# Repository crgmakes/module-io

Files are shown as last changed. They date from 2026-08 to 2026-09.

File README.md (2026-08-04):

# I/O Module

All the source files for the I/O module hardware.

# Software 

You will need [KiCad](https://kicad.org) to view and edit this design. Click [here](https://www.kicad.org/download/) to download.

You will also need all the associated libraries and models to drive the design if you want to make changes or view the 3D rendering:

https://github.com/crgmakes/kicad-library.git

Kicad MUST be configured properly to use all the files in this repo. Once you have Kicad installed, under Preferences->Configure Paths..., make the following entries:

1. KICAD_USER_DIR -> set to the root location of where you placed the above repository.
2. KICAD_USER_LIBRARY = ${KICAD_USER_DIR}/Library
3. KICAD_USER_MODEL_DIR = ${KICAD_USER_LIBRARY}/models
4. KICAD_USER_TEMPLATE_DIR = ${KICAD_USER_LIBRARY}/templates	

Kicad will operate mostly normally if these are not set properly. You will notice an issue when you view the PCB in 3D mode.

***NOTE***: after makeing a release build in git, if your rendered 3D images are missing components, ensure the path to EVERY component model is set to ${KICAD_USER_MODEL_DIR}/<model name>.

Kicad sometimes replaces the variable with an expansion and that FAILS during the build process because the expanded variable is local and does not match the build environment.

---

THE DESIGN IS PROVIDED "AS IS" AND THE AUTHOR DISCLAIMS ALL WARRANTIES WITH REGARD TO THIS DESIGN INCLUDING ALL IMPLIED WARRANTIES OF MERCHANTABILITY AND FITNESS. IN NO EVENT SHALL THE AUTHOR BE LIABLE FOR ANY SPECIAL, DIRECT, INDIRECT, OR CONSEQUENTIAL DAMAGES OR ANY DAMAGES WHATSOEVER RESULTING FROM LOSS OF USE, DATA OR PROFITS, WHETHER IN AN ACTION OF CONTRACT, NEGLIGENCE OR OTHER TORTIOUS ACTION, ARISING OUT OF OR IN CONNECTION WITH THE USE OR PERFORMANCE OF THIS DESIGN.

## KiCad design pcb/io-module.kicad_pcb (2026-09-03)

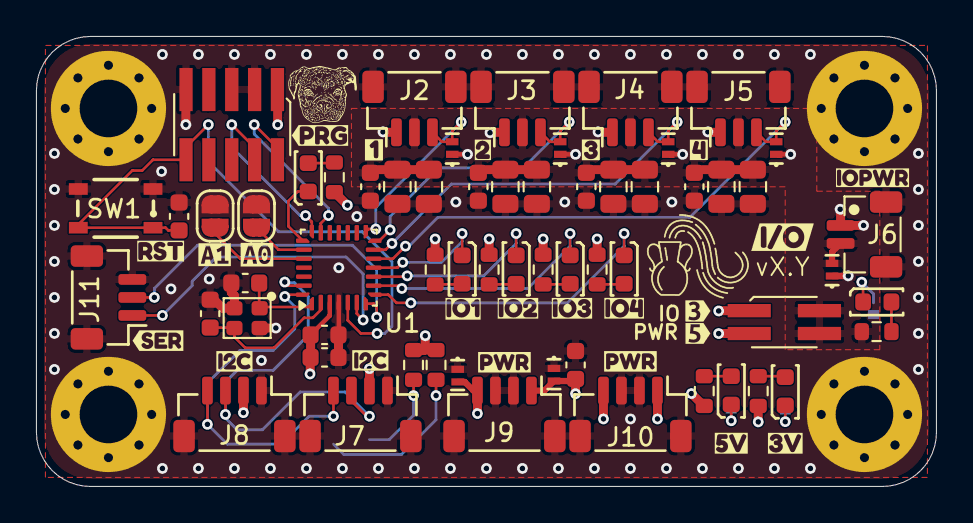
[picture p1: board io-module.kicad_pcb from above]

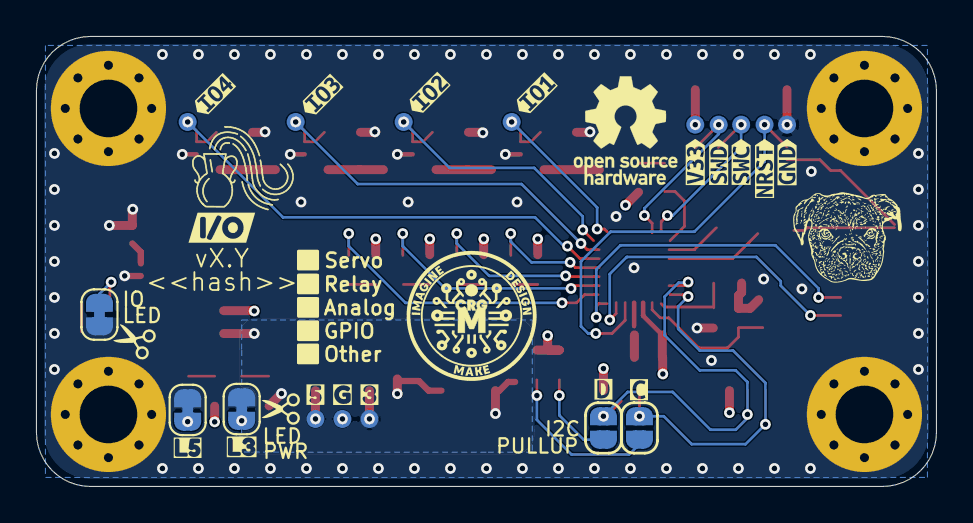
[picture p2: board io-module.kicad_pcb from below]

Board: 4 copper layers, 50.0 x 25.0 mm, 127 parts (38 on the bottom side), 37 nets.

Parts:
C1, C2: 4.7pF; C_0603_1608Metric
C3: 4.7uF; C_0603_1608Metric
C4, C5, C9, C12, C15, C18: 0.1uF; C_0603_1608Metric
C7, C8, C10, C11, C13, C14, C16, C17: 47uF; C_0805_2012Metric
C19: 10uF; C_0603_1608Metric
D1, D2, D3, D4, D12, D13, D14, D15: Blue; LED_0603_1608Metric
D5, D10: PESD5V5C1BL; DFN1006-2
D6, D7, D8, D9, D11: PESD3V3S1BL; DFN1006-2
H1, H2, H3, H4: MountingHole; MountingHole_3.2mm_M3_Pad_Via
J1: SWD Header; PinHeader_2x05_P1.27mm_Vertical_SMD
J2, J3, J4, J5, J11: JST_SH_BM03B-SRSS-TB_1x03-1MP_P1.00mm_Vertical
J6: JST_SH_BM02B-SRSS-TB_1x02-1MP_P1.00mm_Vertical
J7, J8, J9, J10: JST_SH_BM04B-SRSS-TB_1x04-1MP_P1.00mm_Vertical
J12: Conn_02x02_Odd_Even; PinHeader_2x02_P1.27mm_Vertical_SMD
JP1, JP2, JP3, JP4: SolderJumper_2_Open; SolderJumper-2_P1.3mm_Open_RoundedPad1.0x1.5mm
JP6, JP7, JP8: SolderJumper_2_Bridged; SolderJumper-2_P1.3mm_Bridged_RoundedPad1.0x1.5mm
LOGO1, LOGO2: Aquarius Logo 5mm
LOGO3: CRGM Logo 7mm
LOGO4: Logo_Open_Hardware_Small; OSHW-Logo_5.7x6mm_SilkScreen
LOGO5: Roxy 3.5mm
LOGO6: Roxy 6.5mm
R1, R2, R7, R9: 4.7K; R_0603_1608Metric
R3, R4, R5, R6, R8, R10: 1K; R_0603_1608Metric
SW1: SKRPABE010; SMD-4P-4.2x3.2mm
TP1, TP2, TP3, TP9, TP10, TP17, TP18, TP19: TestPoint_Pad_D1.0mm
TP11: SERVO1; TestPoint_Pad_D1.0mm
TP12: SERVO2; TestPoint_Pad_D1.0mm
TP13: SERVO3; TestPoint_Pad_D1.0mm
TP14: SERVO4; TestPoint_Pad_D1.0mm
U1: STM32C051G8Ux; QFN-28_4x4mm_P0.5mm
Y1: ECS-480-10-37B2-RWN-TR; Crystal_SMD_2016-4Pin_2.0x1.6mm
kibuzzard-6A2A39A2: G***; kibuzzard-6A2A39A2
kibuzzard-6A2A39A9: G***; kibuzzard-6A2A39A9
kibuzzard-6A2A39B0: G***; kibuzzard-6A2A39B0
kibuzzard-6A2B43CF: G***; kibuzzard-6A2B43CF
kibuzzard-6A2D8D87: G***; kibuzzard-6A2D8D87
kibuzzard-6A2EE621: G***; kibuzzard-6A2EE621
kibuzzard-6A2EE631: G***; kibuzzard-6A2EE631
kibuzzard-6A540D5A: G***; kibuzzard-6A540D5A
kibuzzard-6A540D7E: G***; kibuzzard-6A540D7E
kibuzzard-6A540D73: G***; kibuzzard-6A540D73
kibuzzard-6A540D79: G***; kibuzzard-6A540D79
kibuzzard-6A540D85: G***; kibuzzard-6A540D85
kibuzzard-6A972EAD: G***; kibuzzard-6A972EAD
kibuzzard-6A972EB4: G***; kibuzzard-6A972EB4
kibuzzard-6A7271F3: G***; kibuzzard-6A7271F3
kibuzzard-6A72720D: G***; kibuzzard-6A72720D
kibuzzard-6A72721E: G***; kibuzzard-6A72721E
kibuzzard-6A72852B: G***; kibuzzard-6A72852B
kibuzzard-6A72853D: G***; kibuzzard-6A72853D
kibuzzard-6A98747D: G***; kibuzzard-6A98747D
kibuzzard-6A727216: G***; kibuzzard-6A727216
kibuzzard-6A727224: G***; kibuzzard-6A727224
kibuzzard-6A727235: G***; kibuzzard-6A727235
kibuzzard-6A727258: G***; kibuzzard-6A727258
kibuzzard-6A728531: G***; kibuzzard-6A728531
kibuzzard-6A728536: G***; kibuzzard-6A728536
kibuzzard-690A7DF7: G***; kibuzzard-690A7DF7
kibuzzard-690A7E03: G***; kibuzzard-690A7E03
kibuzzard-690AC3C6: G***; kibuzzard-690AC3C6
kibuzzard-690AC3CC: G***; kibuzzard-690AC3CC
kibuzzard-690AC3D2: G***; kibuzzard-690AC3D2
kibuzzard-690D5FD9: G***; kibuzzard-690D5FD9
kibuzzard-690D5FF2: G***; kibuzzard-690D5FF2
kibuzzard-6954A310: G***; kibuzzard-6954A310
kibuzzard-6954A315: G***; kibuzzard-6954A315
kibuzzard-691760A0: G***; kibuzzard-691760A0
kibuzzard-6917603D: G***; kibuzzard-6917603D
kibuzzard-6917608E: G***; kibuzzard-6917608E
kibuzzard-69176003: G***; kibuzzard-69176003
kibuzzard-69176035: G***; kibuzzard-69176035

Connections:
+3.3V: C3.1, C4.1, C19.1, D11.2 (K2), J1.1 (VTref), J7.2, J8.2, J9.1 (V3), J10.1 (V3), J12.1, R1.2, R2.2, R3.1, R4.1, R5.1, R6.1, R8.1, R10.1, TP2.1 (1_1), TP18.1 (1_1), U1.3 (VDD)
+5V: D10.2 (K2), J9.4 (V5), J10.4 (V5), J12.3, R7.1, TP17.1 (1_1)
/MCU/A0: JP3.2 (B), U1.23 (PB3)
/MCU/A1: JP4.2 (B), U1.24 (PB4)
/MCU/LED1: D1.1 (K), U1.11 (PA5)
/MCU/LED2: D2.1 (K), U1.10 (PA4)
/MCU/LED3: D3.1 (K), U1.9 (PA3)
/MCU/LED4: D4.1 (K), U1.8 (PA2)
/MCU/STATUS: D15.1 (K), U1.22 (PA15)
/Power/V3.3LED: D13.2 (A), R8.2
/Power/V5LED: D12.2 (A), R7.2
/Power/VIOLED: D14.2 (A), R9.2
GND: C1.1, C2.1, C3.2, C4.2, C5.2, C7.2, C8.2, C9.2, C10.2, C11.2, C12.2, C13.2, C14.2, C15.2, C16.2, C17.2, C18.2, C19.2, D5.1 (K1), D6.1 (K1), D7.1 (K1), D8.1 (K1), D9.1 (K1), D10.1 (K1), D11.1 (K1), H1.1 (1_1), H2.1 (1_1), H3.1 (1_1), H4.1 (1_1), J1.3 (GND), J1.5 (GND), J1.9 (GNDDetect), J2.0 (MP), J2.1, J2.4 (MP), J3.0 (MP), J3.1, J3.4 (MP), J4.0 (MP), J4.1, J4.4 (MP), J5.0 (MP), J5.1, J5.4 (MP), J6.0 (MP), J6.1, J6.3 (MP), J7.0 (MP), J7.1, J7.5 (MP), J8.0 (MP), J8.1, J8.5 (MP), J9.0 (MP), J9.2 (GND), J9.3 (GND), J9.5 (MP), J10.0 (MP), J10.2 (GND), J10.3 (GND), J10.5 (MP), J11.0 (MP), J11.3, J11.4 (MP), JP3.1 (A), JP4.1 (A), JP6.1 (A), JP7.1 (A), JP8.1 (A), SW1.3, SW1.4, TP3.1 (1_1), TP19.1 (1_1), U1.4 (VSS), Y1.2 (G), Y1.4 (G)
IO1: D6.2 (K2), J2.3, TP11.1 (1_1), U1.15 (PB1)
IO2: D7.2 (K2), J3.3, TP12.1 (1_1), U1.14 (PB0)
IO3: D8.2 (K2), J4.3, TP13.1 (1_1), U1.13 (PA7)
IO4: D9.2 (K2), J5.3, TP14.1 (1_1), U1.12 (PA6)
NRST: C5.1, J1.10 (~RESET), SW1.1, SW1.2, TP1.1 (1_1), U1.5 (PF2-NRST)
unnamed: D1.2 (A), R3.2
unnamed: D2.2 (A), R4.2
unnamed: D3.2 (A), R5.2
unnamed: D4.2 (A), R6.2
unnamed: D12.1 (K), JP6.2 (B)
unnamed: D13.1 (K), JP7.2 (B)
unnamed: D14.1 (K), JP8.2 (B)
unnamed: D15.2 (A), R10.2
unnamed: JP1.2 (B), R1.1
unnamed: JP2.2 (B), R2.1
unnamed: C2.2, U1.1 (PC14/OSCXIN), Y1.1
unnamed: C1.2, U1.2 (PC15/OSCXO), Y1.3
RXD: J11.2, U1.7 (PA1)
SCL: J7.4, J8.4, JP1.1 (A), U1.28 (PB8)
SDA: J7.3, J8.3, JP2.1 (A), U1.27 (PB7)
SWCLK: J1.4 (SWDCLK/TCK), TP9.1 (1_1), U1.21 (PA14-BOOT0)
SWDIO: J1.2 (SWDIO/TMS), TP10.1 (1_1), U1.20 (PA13)
TXD: J11.1, U1.6 (PA0)
VIO: C7.1, C8.1, C9.1, C10.1, C11.1, C12.1, C13.1, C14.1, C15.1, C16.1, C17.1, C18.1, D5.2 (K2), J2.2, J3.2, J4.2, J5.2, J6.2, J12.2, J12.4, R9.1

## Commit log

2026-08-04 initial check in
    [interface.kicad_sch, io-module.kicad_pcb, io-module.kicad_sch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]
2026-08-05 Updated parts and IO power connection
    [interface.kicad_sch, io-module.kicad_pcb, io-module.kicad_sch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]
2026-08-05 Fixed directories
    [interface.kicad_sch, io-module.kicad_pcb, io-module.kicad_sch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]
2026-08-05 Updated connector PN, MPN, and model
    [interface.kicad_sch, io-module.kicad_pcb]
2026-08-10 admin changes after prod 1.0
    [io-module.kicad_pcb, mcu.kicad_sch, power.kicad_sch]
2026-09-03 fixes #1 and fixes #2
    [interface.kicad_sch, io-module.kicad_pcb, mcu.kicad_sch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]
2026-09-03 Minor moves
    [io-module.kicad_pcb]
2026-09-03 Ran clean up and DRC
    [io-module.kicad_pcb]
2026-09-03 change version tag
    [io-module.kicad_pcb]
2026-09-04 changed version string
    [io-module.kicad_pcb]
2026-09-04 Updated renders
    Changed <<tag>> to vX.Y
    [interface.kicad_sch, io-module.kicad_pcb, io-module.kicad_sch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]
